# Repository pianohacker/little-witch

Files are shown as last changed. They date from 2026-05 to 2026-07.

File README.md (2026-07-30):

# Little WitCH

The Little WitCH is a tiny but capable dev board for the WCH32V307, boasting:

- The WCH32V307 itself, with a single RISC-V RV32IMACF core
- Gigabit Ethernet via the MXL86110C PHY
- Raspberry-Pi-compatible I/O (with caveats), exposing:
  - Two SPI buses
  - Two I2C buses
  - PCM audio out
  - SDIO/eMMC
  - and/or 28 3.3V GPIO pins
- USB-C 2.0
- USB-1.1 via Raspberry-Pi-Zero-compatible test points
- Tag-Connect TC2030 SWD debugging

## Raspberry Pi compatibility

The WCH32V307's pin remapping can't make it a perfect match for the Raspberry Pi's peripherals. The
biggest caveat is the SPI and PCM outputs, which are all multiplexed together and overlapping:

- SPI3 is exposed on the same pins as the Pi's SPI0 bus.
- PCM is exposed on the same pins as the Pi, but only supports output.
- SPI2 can be exposed on the same pins as the Pi's SPI1 bus, _but_ these pins overlap with the MDIO bus
  of the Ethernet PHY. Also, as these pins overlap with the PCM pins, SPI2 must be switched to by
  cutting and resoldering three solder jumpers below the USB-C port.

That said, this should still allow compatibility with a wide number of Pi Zero / Pi 4 HATs. Will
mention specific examples here as they are tested.

## Solder jumper reconfiguration

There are three sets of solder jumpers that can modify the behavior of this board:

- The jumpers mentioned above, which collectively switch pins 12, 35, and 40 between SPI2 and PCM
  (via I2S3). These default to PCM. **Note:** to be explicit, to switch to SPI2 on these pins, the
  bridge between the first two pads of all three jumpers must be cut and the 2nd and 3rd jumpers
  solder-bridged.
- A jumper to set the value of BOOT1. This defaults to 0.
- A jumper to enable the power LED, which defaults to lit.

## Authors

This is a collaboration between Jesse Weaver (pianohacker) and [Pikkolo Assembly](https://www.pikkoloassembly.com/).

## License

Little WitCH © 2026 by Jesse Weaver is licensed under CC BY-NC-SA 4.0. To view a copy of this license, visit https://creativecommons.org/licenses/by-nc-sa/4.0/

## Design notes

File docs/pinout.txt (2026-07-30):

Raspberry Pi
------------

      +3v3 |  1  2  | +5v
  I2C1 SDA |  3  4  | +5v
  I2C1 SCL |  5  6  | gnd
    GPCLK0 |  7  8  | UART0 TX
       gnd |  9  10 | UART0 RX
      gpio | 11  12 | SPI1 CE0
   SDIO D3 | 13  14 | gnd
  SDIO CLK | 15  16 | SDIO CMD
      +3V3 | 17  18 | SDIO D0
 SPI0 MOSI | 19  20 | gnd
 SPI0 MISO | 21  22 | SDIO D1
 SPI0 SCLK | 23  24 | SPI0 CE0
       gnd | 25  26 | SPIO CE1
EEPROM SDA | 27  28 | EEPROM SCL
    GPCLK1 | 29  30 | gnd
    GPCLK2 | 31  32 | PWM0
      PWM1 | 33  34 | gnd
 SPI1 MISO | 35  36 | SPI1 CE2
   SDIO D2 | 37  38 | SPI1 MOSI
       gnd | 39  40 | SPI1 SCLK

Little WitCH v0.2
-----------------

      +3v3 |  1  2  | +5v
       PA6 |  3  4  | +5v
       PA5 |  5  6  | gnd
       PA4 |  7  8  | PB15
       gnd |  9  10 | PB14
       PB1 | 11  12 | PA8
      PB10 | 13  14 | gnd
      PB11 | 15  16 | PC9
      +3V3 | 17  18 | PA10
       PC6 | 19  20 | gnd
       PC7 | 21  22 | PA9
       PC8 | 23  24 | PC14
       gnd | 25  26 | PC15
      PC13 | 27  28 | PB9
       PB8 | 29  30 | gnd
       PB5 | 31  32 | PB4
       PB3 | 33  34 | gnd
      PC12 | 35  36 | PD2
      PC10 | 37  38 | PC11
       gnd | 39  40 | PA15

Little WitCH v0.3 candidates
----------------------------

Note: 1-wire is not natively supported.

        +3v3 |  1  2  | +5v
         B11 |  3  4  | +5v
         B10 |  5  6  | gnd
          B1 |  7  8  | A9
         gnd |  9  10 | A10
        gpio | 11  12 | B12   
         C11 | 13  14 | gnd
         C12 | 15  16 | D2
        +3V3 | 17  18 | C8
          B5 | 19  20 | gnd
          B4 | 21  22 | C9
          B3 | 23  24 | A15   
         gnd | 25  26 | gpio
          B9 | 27  28 | B8
         C13 | 29  30 | gnd
         C14 | 31  32 | C15
          C7 | 33  34 | gnd
         B14 | 35  36 | gpio
         C10 | 37  38 | B15  
         gnd | 39  40 | B13      

Little WitCH v0.3
-----------------

- RPI I2C1 -> WCH32V307 I2C2
- RPI EEPROM I2C -> WC32V307 I2C1
- RPI SPI0 -> WCH32V307 SPI3
- RPI SPI1 -> WCH32V307 SPI2 (conflicts with Ethernet)
- RPI PCM -> WCH32V307 I2S3 (_not_ conflicting with Ethernet but multiplexed onto SPI2 pins and
  preventing use of SPI3)

      +3v3 |  1  2  | +5v
       B11 |  3  4  | +5v
       B10 |  5  6  | gnd
        B1 |  7  8  | A9
       gnd |  9  10 | A10
        A4 | 11  12 | B12
       C11 | 13  14 | gnd
       C12 | 15  16 | D2
      +3V3 | 17  18 | C8
        B5 | 19  20 | gnd
        B4 | 21  22 | C9
        B3 | 23  24 | A15
       gnd | 25  26 | A5
        B9 | 27  28 | B8
       C13 | 29  30 | gnd
       C14 | 31  32 | C15
        C7 | 33  34 | gnd
       B14 | 35  36 | A6
       C10 | 37  38 | B15
       gnd | 39  40 | B13

NOTE: SPI1 conflicts with Ethernet MDIO.

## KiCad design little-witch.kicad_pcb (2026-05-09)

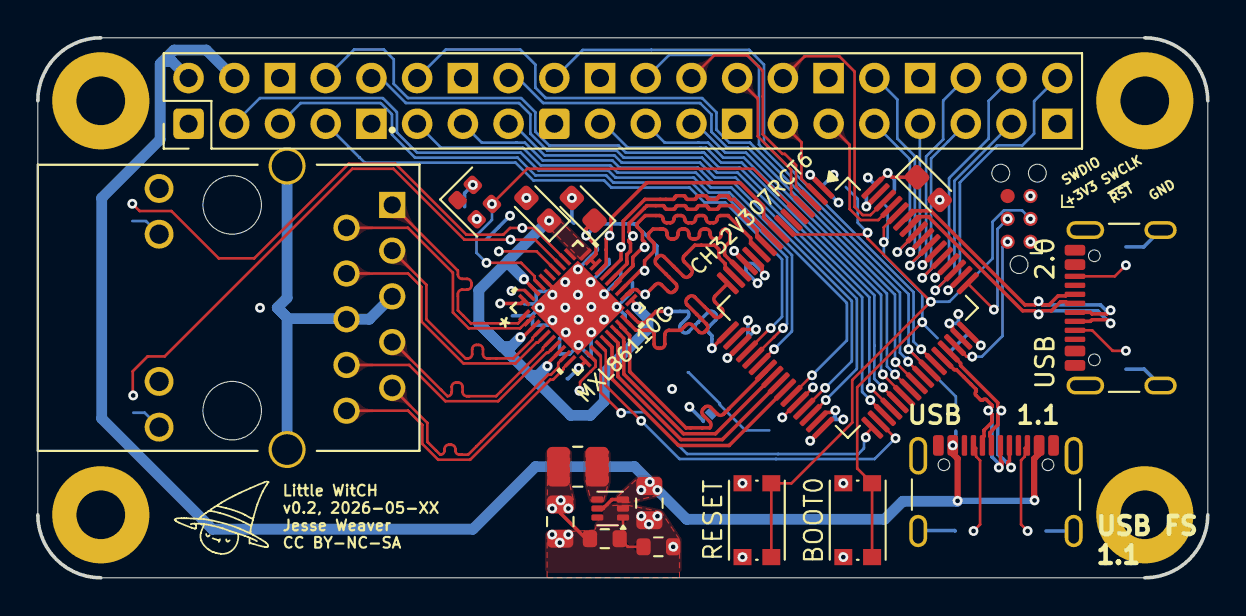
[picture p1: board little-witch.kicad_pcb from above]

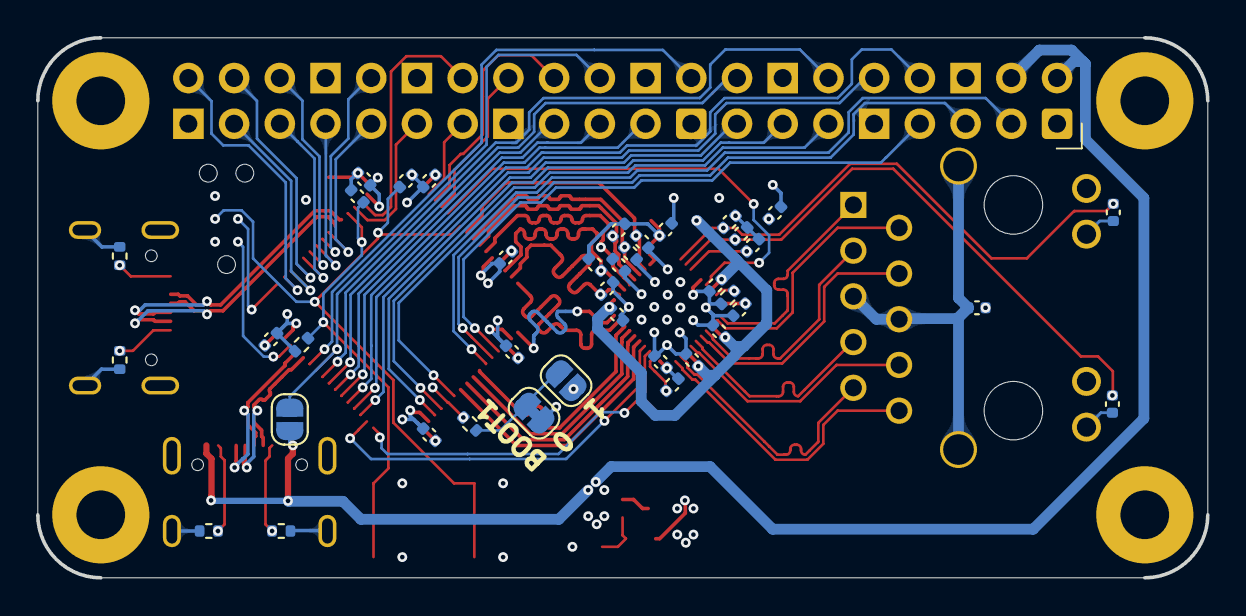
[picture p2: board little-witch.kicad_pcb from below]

Board: 4 copper layers, 65.0 x 30.0 mm, 62 parts (40 on the bottom side), 79 nets.

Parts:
C1, C7, C10: 10u; CP_EIA-2012-12_Kemet-R
C2, C3, C4, C5, C6, C8, C9, C11, C14, C18, C19, C20, C22, C23, C24, C26, C27: 100n; C_0402_1005Metric
C12: 4.7u; C_0805_2012Metric
C13: 22u; C_0805_2012Metric
H1, H2, H3, H4: MountingHole_Pad; MountingHole_2.7mm_M2.5_Pad
J1, J4: GCT-USB4105; USB_C_Receptacle_GCT_USB4105-xx-A_16P_TopMnt_Horizontal
J2: TMJG0803HENL; RJ45_TMJG0803HENL
J3: Conn_ARM_SWD_TagConnect_TC2030-NL; Tag-Connect_TC2030-IDC-NL_2x03_P1.27mm_Vertical
J5: Conn_02x20_Odd_Even; PinHeader_2x20_P2.54mm_Vertical
JP3, JP5: SolderJumper_2_Open; SolderJumper-2_P1.3mm_Open_RoundedPad1.0x1.5mm
JP4: SolderJumper_2_Open; SolderJumper-2_P1.3mm_Bridged_RoundedPad1.0x1.5mm
L1: 1u; L_1008_2520Metric
R3, R4, R8, R9: 5.1k; R_0402_1005Metric
R5, R17, R18, R19, R20, R21, R22: 1K; C_0402_1005Metric
R7, R10: 10k; R_0402_1005Metric
R11, R12: 100; C_0402_1005Metric
R13: 2.49K ±1%; R_0402_1005Metric
R14, R15, R16: 4.7K; C_0402_1005Metric
R23: 453K ±1%; R_0603_1608Metric
R24: 100K ±1%; R_0603_1608Metric
SW1: RESET; SW_Push_1P1T_NO_CK_KMR2
SW2: BOOT0; SW_Push_1P1T_NO_CK_KMR2
U1: CH32V307RCT6; LQFP-64_10x10mm_P0.5mm
U2: MXL86110C-AQB-R; QFN40_5X5_MXL
U3: TPS62A0568PDRLR; SOT-563
Y1: SIT8008BI-73-33N-25.000000; Oscillator_SMD_SiT_PQFN-4Pin_2.0x1.6mm

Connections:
+3V3: C1.1, C2.1, C3.1, C4.1, C5.1, C6.1, C9.1, C10.1, C11.1, C13.1, C14.1, C20.1, C22.1, C23.1, J2.11, J2.13, J3.1 (VCC), J5.1, J5.17, JP3.1 (A), L1.2, R5.2, R14.1, R15.1, R16.1, R21.1, R22.1, R23.2, SW2.1, U1.1 (VBAT), U1.13 (VDDA), U1.19 (VDD_4), U1.32 (VIO_1), U1.48 (VDD_2), U1.64 (VIO_3), U2.11 (VDDA3V3), U2.28 (VDDP), U2.29 (VDD3V3), U2.40 (VDDA3V3), Y1.4 (Vdd)
/ETH_CFG_LDO1: R16.2, U2.34 (GPHY_LED2/CFG_LDO1)
/ETH_SHIELD: C27.1, J2.5 (CT), J2.6 (CT__1), J2.SH (SHIELD)
/PA4: J5.7, U1.20 (DAC0/ADC4/PA4)
/PA5: J5.5, U1.21 (DAC1/ADC5/PA5)
/PA6: J5.3, U1.22 (ADC6/PA6)
/PA8: J5.12, U1.41 (PA8)
/PA9: J5.22, JP5.2 (B), U1.42 (PA9)
/PA10: J5.18, U1.43 (PA10)
/PA15: J5.40, U1.50 (PA15)
/PB1: J5.11, U1.27 (ADC9/PB1)
/PB2: R7.2, U1.28 (BOOT1/PB2)
/PB3: J5.33, U1.55 (PB3)
/PB4: J5.32, U1.56 (PB4)
/PB5: J5.31, U1.57 (PB5)
/PB8: J5.29, U1.61 (PB8)
/PB9: J5.28, U1.62 (PB9)
/PB10: J5.13, U1.29 (PB10)
/PB11: J5.15, U1.30 (PB11)
/PB14: J5.10, U1.35 (PB14)
/PB15: J5.8, U1.36 (PB15)
/PC6: J5.19, U1.37 (PC6/RXP)
/PC7: J5.21, U1.38 (PC7/RXN)
/PC8: J5.23, U1.39 (PC8/TXP)
/PC9: J5.16, U1.40 (PC9/TXN)
/PC10: J5.37, U1.51 (PC10)
/PC11: J5.38, U1.52 (PC11)
/PC12: J5.35, U1.53 (PC12)
/PC13: J5.27, U1.2 (PC13/TAMPER-RTC)
/PC14: J5.24, U1.3 (PC14/OSC32_IN)
/PC15: J5.26, U1.4 (PC15/OSC32_OUT)
/PD2: J5.36, U1.54 (PD2)
/TD1+: J2.1 (TD1+), U2.1 (TPIAP)
/TD1-: J2.2 (TD1-), U2.2 (TPIAN)
/TD2+: J2.3 (TD2+), U2.4 (TPIBP)
/TD2-: J2.4 (TD2-), U2.5 (TPIBN)
/TD3+: J2.7 (TD3+), U2.6 (TPICP)
/TD3-: J2.8 (TD3-), U2.7 (TPICN)
/TD4+: J2.9 (TD4+), U2.9 (TPIDP)
/TD4-: J2.10 (TD4-), U2.10 (TPIDN)
ETH_LED1: R11.2, R14.2, U2.32 (GPHY_LED0/CFG_EXT)
ETH_LED2: R12.2, R15.2, U2.33 (GPHY_LED1/CFG_LDO0)
ETH_MDC: U1.33 (PB12), U2.13 (MDC)
ETH_MDIO: U1.34 (PB13), U2.14 (MDIO)
ETH_RESET: R5.1, U2.12 (HRSTN)
ETH_RXC: R20.2, U1.8 (PC0/ADC10), U2.27 (RX_CLK/PHYAD1)
ETH_RXD0: R21.2, U1.10 (PC2/ADC12), U2.25 (RXD0/RXDLY)
ETH_RXD1: R19.2, U1.11 (PC3/ADC13), U2.24 (RXD1/TXDLY)
ETH_RXD2: R22.2, U1.14 (ADC0/WKUP/PA0), U2.23 (RXD2/PLLOFF)
ETH_RXD3: R17.2, U1.15 (ADC1/PA1), U2.22 (RXD3/PHYAD0)
ETH_RX_CTL: R18.2, U1.9 (PC1/ADC11), U2.26 (RX_CTL/PHYAD2)
ETH_TXC: U1.16 (ADC2/PA2), U2.19 (TX_CTL)
ETH_TXD0: U1.23 (ADC7/PA7), U2.18 (TXD0)
ETH_TXD1: U1.24 (PC4/ADC14), U2.17 (TXD1)
ETH_TXD2: U1.25 (PC5/ADC15), U2.16 (TXD2)
ETH_TXD3: U1.26 (ADC8/PB0), U2.15 (TXD3)
ETH_TX_CTL: U1.17 (ADC3/PA3), U2.20 (TX_CLK)
GND: C1.2, C2.2, C3.2, C4.2, C5.2, C6.2, C7.2, C8.1, C9.2, C10.2, C11.2, C12.2, C13.2, C18.2, C19.2, C20.2, C22.2, C23.2, C24.2, C26.2, C27.2, H1.1 (1_1), H2.1 (1_1), H3.1 (1_1), H4.1 (1_1), J1.A1 (GND), J1.A12 (GND), J1.B1 (GND), J1.B12 (GND), J1.SH (SHIELD), J3.5 (GND), J4.A1 (GND), J4.A12 (GND), J4.B1 (GND), J4.B12 (GND), J4.SH (SHIELD), J5.6, J5.9, J5.14, J5.20, J5.25, J5.30, J5.34, J5.39, JP4.1 (A), R3.2, R4.1, R8.2, R9.1, R10.1, R13.2, R17.1, R18.1, R19.1, R20.1, R24.1, SW1.1, U1.12 (VSSA), U1.18 (VSS_4), U1.31 (VSS_1), U1.47 (VSS_2), U1.63 (VSS_3), U2.36 (XTAL1), U2.41 (GND), U3.2 (GND), Y1.2 (GND)
NRST: C8.2, J3.3 (~RESET), SW1.2, U1.7 (NRST)
unnamed: J1.A5 (CC1), R3.1
unnamed: J1.B5 (CC2), R4.2
unnamed: J2.12, R11.1
unnamed: J2.14, R12.1
unnamed: J4.A5 (CC1), R8.1
unnamed: J4.B5 (CC2), R9.2
unnamed: JP3.2 (B), JP4.2 (B), R7.1
unnamed: C14.2, R10.2, SW2.2, U1.60 (BOOT0)
unnamed: R13.1, U2.39 (RCAL)
unnamed: R23.1, R24.2, U3.1 (FB)
unnamed: L1.1, U3.4 (SW)
SWCLK: J3.4 (SWCLK), U1.49 (SWCLK/PA14)
SWDIO: J3.2 (SWDIO), U1.46 (SWDIO/PA13)
SYS_CLK: U1.5 (OSC_IN/PD0), U2.37 (XTAL2/CLK), Y1.3 (OUT)
USB1_DN: J1.A7 (D-), J1.B7 (D-), U1.44 (USB1_DM/PA11)
USB1_DP: J1.A6 (D+), J1.B6 (D+), U1.45 (USB1_DP/PA12)
USB1_VBUS: C12.1, J1.A4 (VBUS), J1.A9 (VBUS), J1.B4 (VBUS), J1.B9 (VBUS), J5.2, J5.4, JP5.1 (A), U3.3 (VIN), U3.5 (EN)
USB2_DN: J4.A7 (D-), J4.B7 (D-), U1.58 (USB2_DM/PB6)
USB2_DP: J4.A6 (D+), J4.B6 (D+), U1.59 (USB2_DP/PB7)
VDD_ETH: C7.1, C18.1, C19.1, C24.1, C26.1, U2.3 (VDDA1V1), U2.8 (VDDA1V1), U2.21 (VDD), U2.30 (DCDC_REGO), U2.38 (VDDA1V1)

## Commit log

2026-04-17 Add 3d model to kycon footprint
2026-04-24 v0.1 without Ethernet or voltage reg
    [ethernet.kicad_sch, little-witch.kicad_pcb, little-witch.kicad_sch]
2026-04-28 Import all symbols into project library
    [ethernet.kicad_sch, little-witch.kicad_pcb, little-witch.kicad_sch]
2026-04-28 Remove core symbols from project library
    [ethernet.kicad_sch]
2026-04-29 Start of ethernet
    [ethernet.kicad_sch, little-witch.kicad_pcb]
2026-04-30 Ethernet schematic done
    [ethernet.kicad_sch, little-witch.kicad_pcb, little-witch.kicad_sch]
2026-04-30 Base ethernet signals routed
    [ethernet.kicad_sch, little-witch.kicad_pcb, little-witch.kicad_sch]
2026-04-30 First ethernet jack routed
    [little-witch.kicad_pcb]
2026-05-01 Etherent MDI rerouted with correct trace widths
    [ethernet.kicad_sch, little-witch.kicad_pcb]
2026-05-01 MDI RX/TX length matched
    [little-witch.kicad_pcb]
2026-05-01 USB routing
    [little-witch.kicad_pcb]
2026-05-01 MCU decoupling
    [little-witch.kicad_pcb]
2026-05-01 Start on PHY decoupling
    [little-witch.kicad_pcb]
2026-05-01 More PHY passives
    [ethernet.kicad_sch, little-witch.kicad_pcb]
2026-05-02 PHY RX routing and power
    [ethernet.kicad_sch, little-witch.kicad_pcb]
2026-05-02 Ethernet shielding
    [ethernet.kicad_sch, little-witch.kicad_pcb]
2026-05-03 Some GPIO and power routing
    [little-witch.kicad_pcb, little-witch.kicad_sch]
2026-05-03 Continued GPIO
    [little-witch.kicad_pcb, little-witch.kicad_sch]
2026-05-04 Shrink vias to 0.55mm
    [little-witch.kicad_pcb]
2026-05-06 GPIO routing
    [little-witch.kicad_pcb, little-witch.kicad_sch]
2026-05-06 More GPIO routing
    [little-witch.kicad_pcb, little-witch.kicad_sch]
2026-05-07 Yet more GPIO routing
    [little-witch.kicad_pcb, little-witch.kicad_sch]
2026-05-07 GPIO fully routed
    [little-witch.kicad_pcb, little-witch.kicad_sch]
2026-05-07 Ethernet LEDs and start of power
    [little-witch.kicad_pcb]
2026-05-07 Routing tweaks
    [little-witch.kicad_pcb]
2026-05-08 Start of better GPIO routing
    [little-witch.kicad_pcb]
2026-05-08 Better GPIO routing
    [little-witch.kicad_pcb, little-witch.kicad_sch]
2026-05-08 Power regulation
    [little-witch.kicad_pcb, little-witch.kicad_sch]
2026-05-08 Debug routing
    [little-witch.kicad_pcb, little-witch.kicad_sch]
2026-05-08 Reset and BOOT0 buttons
    [little-witch.kicad_pcb]
2026-05-08 Missing power schematic
    [little-witch.kicad_pcb, power.kicad_sch]
2026-05-08 USB VBUS diode
    [little-witch.kicad_sch]
2026-05-09 Silkscreen tweaks
    [little-witch.kicad_pcb]
2026-05-09 Final silkscreen, v0.2
    [little-witch.kicad_pcb]
2026-07-11 Start of USB changes
    [little-witch.kicad_sch]
2026-07-13 Start of changes for v0.3
    - Drop USB FS for unpopulated header
    - Add LEDs
    - Tweak BOOT0 debouncing
    [little-witch.kicad_sch]
2026-07-17 Continued pin choice work
    [little-witch.kicad_sch]
2026-07-17 More pin assignments
    [little-witch.kicad_sch]
2026-07-17 Finish pin assignment
    [little-witch.kicad_sch]
2026-07-19 Power/LED tweaks, GPIO routing
    [little-witch.kicad_sch]
2026-07-21 v0.3.0 with gpio routing, updated labeling, leds
    [little-witch.kicad_sch]
2026-07-29 PCM multiplexing before USB rework
    [little-witch.kicad_sch]
2026-07-29 PCM multiplexing routing done
    [little-witch.kicad_sch]
2026-07-29 VBUS trace width tweaks
2026-07-30 v0.3.1: Final tweaks to silkscreen/jumpers, add README
    [little-witch.kicad_sch]
2026-07-30 v0.3.2: Move power reg away from Ethernet
